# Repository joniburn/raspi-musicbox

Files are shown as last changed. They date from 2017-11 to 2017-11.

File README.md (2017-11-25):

# Raspberry Piで音楽を演奏する

[Googleスライド](https://docs.google.com/presentation/d/1v06TiHg_VfW_GpwTSDZcnkdz5-jW30KUHXwWN1498sA/)

## 必要なもの
* Raspberry Pi 3 Model B
* 発音部品: 以下を同時発音数の数だけ
  * パッシブブザー
    * https://www.amazon.co.jp/dp/B01AJQE1N6/
  * 抵抗 200Ω
  * 電界効果トランジスタ(FET): 2N7000
    * https://www.amazon.co.jp/gp/product/B018FRALXA/
* 半固定抵抗: ボリューム調節のため(オプション)
* ブレッドボードや配線用ジャンパワイヤ
  * https://www.amazon.co.jp/gp/product/B01M6ZFNSS/
* その他LANケーブル等

## 配線図
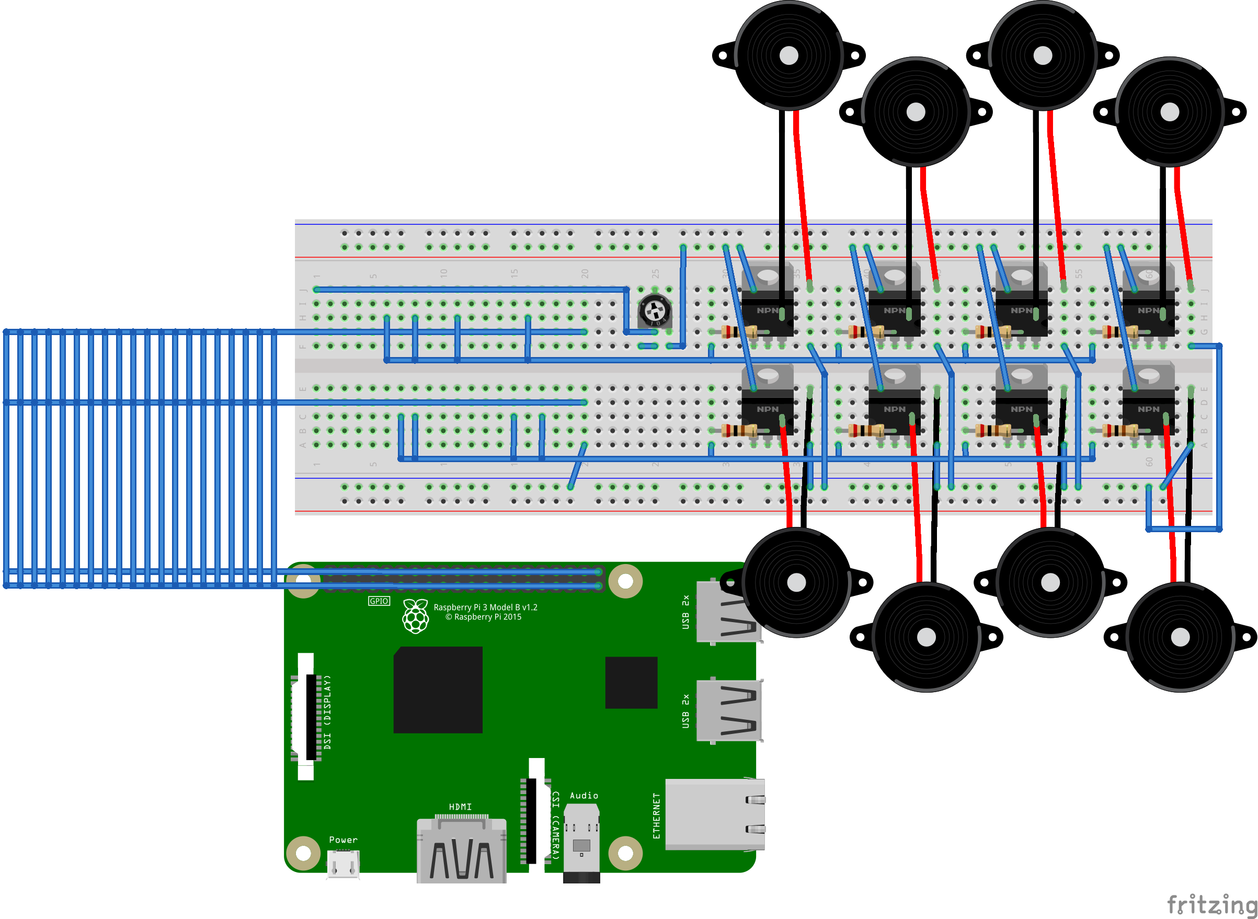
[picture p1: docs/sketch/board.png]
配線図


## 環境
* OS
  * Raspbian Stretch
* インストールするパッケージ
  * [pyenvの依存パッケージ](https://github.com/pyenv/pyenv/wiki/Common-build-problems)
    * make
    * build-essential
    * libssl-dev
    * zlib1g-dev
    * libbz2-dev
    * libreadline-dev
    * libsqlite3-dev
    * wget
    * curl
    * llvm
    * libncurses5-dev
    * libncursesw5-dev
    * xz-utils
    * tk-dev
* Python
  * pyenvでPython 3.6.3をインストール

## コンパイル

    cd gpiosound
    make

コンパイルでできるバイナリ
* gpiosound
  * GPIOピン1つを担当し、音が出るように出力レベルをトグルしまくるプロセス。
  * 標準入力から32bit浮動小数点数を読み取り、その値を周波数として音を出力する。
* writefloat
  * gpiosoundのテスト用ツール。
  * コマンドライン引数で指定した浮動小数点数を標準出力に出力する。
  * 周波数440Hzの音を2秒間鳴らす例:
    * `( ./writefloat 440.0; sleep 2 ) | ./gpiosound -o 18`

## 楽譜ファイルを演奏する

    cd python-musicbox
    python -m musicbox.main ../score/disksystem.txt

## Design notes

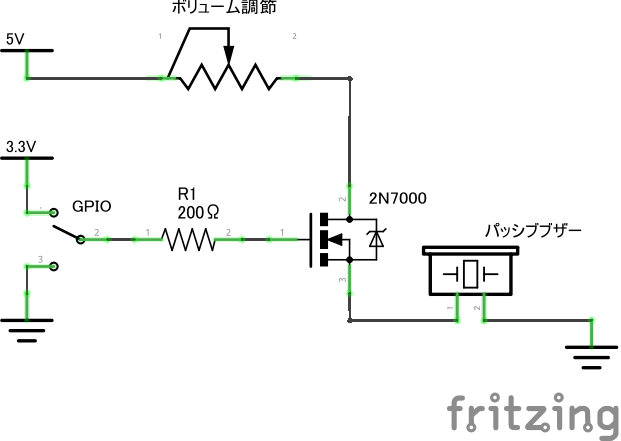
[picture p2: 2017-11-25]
docs/sketch/unit_circuit.png

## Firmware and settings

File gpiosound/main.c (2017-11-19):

#include <stdio.h>
#include <stdlib.h>
#include <unistd.h>
#include <string.h>
#include <assert.h>
#include <fcntl.h>
#include <errno.h>
#include <sys/epoll.h>
#include <arpa/inet.h>

#include "optparse.h"
#include "sound.h"
#include "tone.h"
#include "noise.h"
#include "log.h"

#define MAX_EVENTS 2

static int init_epoll(int timerfd);

int main(int argc, char *argv[]) {
  // 引数パース
  options opt;
  parse_args(argc, argv, &opt);

  printf("outpin=%d, dutyratio=%d\n", opt.outpin, opt.dutyratio);

  sound s;
  switch (opt.mode) {
    case SOUND_MODE_TONE: {
      s = sound_tone;
      break;
    }
    case SOUND_MODE_NOISE: {
      s = sound_noise;
      break;
    }
    case SOUND_MODE_UNKNOWN:  // fall through
    default: {
      printf("unknown play mode.\n");
      return EXIT_FAILURE;
    }
  }

  // ファイルディスクリプタの初期化
  int timerfd = s.init(&opt);
  int epollfd = init_epoll(timerfd);

  // 標準入力をノンブロックに設定する
  int cur = fcntl(STDIN_FILENO, F_GETFL);
  if (cur == -1) {
    perror("fcntl");
    return EXIT_FAILURE;
  }
  int ret = fcntl(STDIN_FILENO, F_SETFL, cur | O_NONBLOCK);
  if (ret == -1) {
    perror("fcntl");
    return EXIT_FAILURE;
  }

  // メインループ
  uint32_t stdin_buf = 0;
  size_t stdin_read_bytes = 0;
  while (1) {
    struct epoll_event events[MAX_EVENTS];
    int nfds;

    nfds = epoll_wait(epollfd, events, MAX_EVENTS, -1);
    assert(nfds <= MAX_EVENTS);
    if (nfds == -1) {
      perror("epoll_wait");
      return EXIT_FAILURE;
    }
    for (int i = 0; i < nfds; i++) {
      int fd = events[i].data.fd;

      // タイマーが発火: tone()を呼ぶ
      if (fd == timerfd) {
        s.do_sound();
      }

      // 標準入力: 2バイト読んだ数値を周波数としてセットする
      else if (fd == STDIN_FILENO) {
        ssize_t read_bytes = read(STDIN_FILENO,
                                  ((uint8_t *) &stdin_buf) + stdin_read_bytes,
                                  sizeof(stdin_buf) - stdin_read_bytes);
        if (read_bytes == -1) {
          if (errno == EAGAIN) {
            continue;
          }
          perror("read");
          return EXIT_FAILURE;
        }
        if (read_bytes == 0) {
          // end of file
          printf("exitting by end of file.\n");
          return EXIT_SUCCESS;
        }
        stdin_read_bytes += (size_t) read_bytes;
        debug("stdin_read_bytes=%u, stdin_buf=[%u, %u, %u, %u]\n", stdin_read_bytes,
              ((uint8_t *) &stdin_buf)[0], ((uint8_t *) &stdin_buf)[1],
              ((uint8_t *) &stdin_buf)[2], ((uint8_t *) &stdin_buf)[3]);

        if (stdin_read_bytes >= 4) {
          // floatのバイトオーダー変換
          float in;
          uint32_t converted = ntohl(stdin_buf);
          memcpy(&in, &converted, sizeof(stdin_buf));
          debug("converted=%ul, in=%f\n", converted, (double) in);
          s.setfreq(in);
          stdin_read_bytes = 0;
          stdin_buf = 0;
        }
      }
    }
  }

  return EXIT_SUCCESS;
}

// メインループ処理のためのepoll初期化
static int init_epoll(int timerfd) {
  int ret;

  int epollfd = epoll_create1(0);
  if (epollfd == -1) {
    perror("epoll_create1");
    exit(EXIT_FAILURE);
  }

  // 監視対象fdその1: 標準入力
  struct epoll_event ev1 = {EPOLLIN | EPOLLET, {0}};
  ev1.data.fd = STDIN_FILENO;
  ret = epoll_ctl(epollfd, EPOLL_CTL_ADD, STDIN_FILENO, &ev1);
  if (ret == -1) {
    perror("epoll_ctl");
    exit(EXIT_FAILURE);
  }

  // 監視対象fdその2: タイマー
  struct epoll_event ev2 = {EPOLLIN | EPOLLET, {0}};
  ev2.data.fd = timerfd;
  ret = epoll_ctl(epollfd, EPOLL_CTL_ADD, timerfd, &ev2);
  if (ret == -1) {
    perror("epoll_ctl");
    exit(EXIT_FAILURE);
  }
  return epollfd;
}

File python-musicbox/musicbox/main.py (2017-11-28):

import os.path
import sys
from multiprocessing import Process
from subprocess import Popen, PIPE
from struct import pack
from time import sleep
from datetime import datetime

from musicbox.score import Score


# パッシブブザーに配線されているGPIOピン
PIN = [27, 22, 18, 23, 25, 12, 5, 13]
# 実行ファイル
SOUND_EXEC = os.path.join('..', 'gpiosound', 'gpiosound')


def usage(progname: str):
    print(f'Usage: {progname} SCORE_FILE')
    exit(0)


def playtrack(score: Score, track: int):
    props = score.prop(track)
    mode = props.mode  # "tone" or "noise"
    outpin = str(PIN[track])
    args = [SOUND_EXEC, mode, outpin]
    if props.duty:
        args.extend(['-d', str(props.duty)])
    with Popen(args, bufsize=0, stdin=PIPE) as p:
        for freq, nexttime in score.build_timeline(track):
            # print(f'freq={freq}, nexttime={nexttime}')
            p.stdin.write(pack('!f', freq))
            now = datetime.now()
            sleepsec = (nexttime - now).total_seconds()
            if sleepsec > 0:
                sleep(sleepsec)


def main():
    if len(sys.argv) != 2:
        usage(sys.argv[0])
    score_file = sys.argv[1]

    # スコアファイルの読み込み
    score = Score(score_file)

    # トラック数チェック
    if score.ntrack > len(PIN):
        raise Exception('no sufficient output pin is provided.')

    # トラック毎にtoneserverと通信するプロセスをfork
    processes = []
    for track in range(0, score.ntrack):
        p = Process(target=playtrack, args=(score, track))
        p.start()
        processes.append(p)
    for p in processes:
        p.join()
    print('All subprocesses finished.')


if __name__ == '__main__':
    main()

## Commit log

2017-11-11 引数パース処理を実装
2017-11-11 標準入力から2バイトずつ読み込む処理を実装
2017-11-12 入力EOF処理を追加
2017-11-12 toneserverのディレクトリを１階層下げる
2017-11-12 引数パース処理を別ファイルに分離
2017-11-12 .gitignoreにコンパイル結果の実行ファイルを追加
2017-11-12 音を鳴らす処理の初期化
2017-11-12 音が鳴るように修正
2017-11-12 Makefileにcleanを追加
2017-11-12 ヘッダファイルのdefineミス修正
2017-11-12 標準入力から読み込む周波数の型を uint16_t から float に変更
2017-11-12 テスト用にfloat型で周波数を出力するプログラムを作成
2017-11-12 スコアファイルの読み込み処理を実装
2017-11-12 toneserverをフォークして周波数を送る処理を実装
2017-11-12 楽譜から周波数のタイムラインを生成する処理を実装
2017-11-13 和音に対応
2017-11-13 スコア中の桁揃えのための空白を無視
2017-11-13 ディスクシステム
2017-11-13 ノイズを鳴らすCプログラム
    TODO コピペなので共通化する
2017-11-13 ディスクシステムにノイズトラック追加
2017-11-14 ディスクシステム起動音のﾎﾟﾛﾛｯ
2017-11-14 音階を1オクターブ間違えていたのを修正
2017-11-14 サウンドテストとして全音階を鳴らす
2017-11-14 デューティ比を指定する機能を追加
    でもあんまり音が代り映えしないかも。
2017-11-14 Fix: プロセスのフォークに失敗することがある
2017-11-14 FF5メインテーマ(途中)
2017-11-17 Fix: noiseserver初期化時にピン出力モードを設定できない
2017-11-17 8和音分のピンを設定
2017-11-19 Refactor: Cソースファイル名整理
2017-11-19 Makefile修正
2017-11-19 .gitignore更新
2017-11-19 強化したwarnオプションに対応
2017-11-19 さらにwarnオプションを強化
2017-11-19 引数パース処理を更新
2017-11-19 リファクタリング
2017-11-19 実行ファイルIF変更に対応
2017-11-19 BPMの途中変更に対応
2017-11-19 楽譜のCSV対応、ノイズトラックの指定
2017-11-19 Romantic Children(途中)
2017-11-19 Romantic Children完成
2017-11-19 ノイズテスト用ファイル
2017-11-19 DEBUGログを黙らせる
2017-11-19 楽譜ファイルフォーマット変更に対応
2017-11-19 FF5メインテーマ
2017-11-25 Romantic Childrenのループ再生
2017-11-25 ドキュメント更新
    [board.fzz, unit.fzz]
2017-11-25 お風呂が沸いたときの曲
2017-11-25 お風呂バトル#2
2017-11-26 Super Depth和音版
2017-11-26 Super Depth単音版
2017-11-27 Fix: "x 16 1"を10行分と"x 8 5"を1行分にずれが生じる
    [score.py]
2017-11-27 グリーングリーンズ(途中)
2017-11-28 楽譜ファイルでduty比を指定する機能を追加
2017-11-28 グリーングリーンズ
2017-11-29 危機(前半まで)
2017-11-29 危機(サビ途中)
2017-11-30 危機(完成)
